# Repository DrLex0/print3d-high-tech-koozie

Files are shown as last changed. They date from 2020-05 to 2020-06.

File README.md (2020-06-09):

# High-tech Koozie (customizable)
*3D printable Customizable high-tech cooler (koozie) for cans and bottles (formerly thing:1771124 and thing:3927994)*

### License
[Creative Commons - Attribution - Non Commercial - Share Alike](https://creativecommons.org/licenses/by-nc-sa/4.0/)

For the legally impaired: my interpretation of the *non-commercial* aspect of this license, is that you cannot make profits from either the 3D models generated by this customizer, or physical 3D prints. Read the entire LICENSE file for the fine details. I have no objections against selling 3D prints of this model at no more than strictly the cost of used material and electricity.

### Gallery

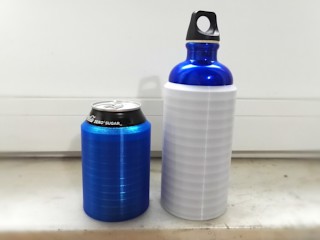
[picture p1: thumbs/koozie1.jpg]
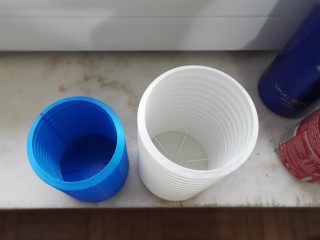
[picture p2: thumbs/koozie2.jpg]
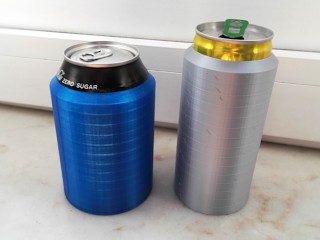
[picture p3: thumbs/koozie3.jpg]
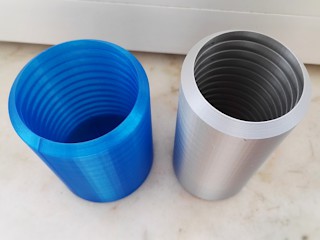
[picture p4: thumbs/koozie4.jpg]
[🔎](images/koozie1.jpg) [🔎](images/koozie2.jpg) [🔎](images/koozie3.jpg) [🔎](images/koozie4.jpg)

## Description and Instructions

OK, I admit, it's just a piece of plastic, therefore ‘high tech’ may be a bit exaggerated.
Still, this is not your average soda can cooler, or ‘koozie’ as it is sometimes called. This one has no inner shell, instead it relies on the can itself to seal the air inside. This has the benefit of minimizing the material needed hence lighter weight, as well as a minimal contact area with the plastic such that it maximally relies on air for insulation: air is a better thermal insulator than most if not all plastics. To further improve insulation, the zone between the can and the outer walls is divided into horizontal compartments to reduce convection.

This is a **customizable parametric model** made in OpenSCAD. A ready-to-print model for the ubiquitous 330 ml can can be found in the examples folder, but if you have a different size of can or bottle, just **[use OpenSCAD's Customizer](https://www.dr-lex.be/3d-printing/customizer.html)** to generate a model tailored to it. The only condition is that the bottle's lower part is a nearly perfect cylinder.

When creating your own model in Customizer, the most important parameters are the diameter of the can and its height you want to be covered by the koozie. To get a tight fit without having to push or tug on the can, make sure to either accurately measure the diameter, or just look it up in specification sheets from can or bottle manufacturers. The JSON file contains a few presets with accurate diameters that can be loaded in the customizer interface inside OpenSCAD.
The *air gap* determines the distance between the outside of the can/bottle (plus tolerance) and the outer wall. I usually set this to between 4 and 5 mm. More will obviously offer better insulation, but also makes the thing fatter and unwieldy.

This works equally well in rigid and flexible filaments. A flexible filament is recommended for robustness, for instance the koozie for the SIGG bottle in the photos was printed with rigid.ink flexible PLA.

Depending on what material you print in, to compensate for shrinkage of the material when it cools down after printing, you may need to slightly scale up the model or generate it with either a larger tolerance or larger diameter. Flexible filaments tend to shrink considerably but since they're flexible, it usually also isn't too bad if the model is slightly too tight. To avoid spending hours and material on a print and then noticing it is too tight or sloppy, the customizer has an option `test_slice` that will generate a minimal model that can be quickly printed for testing the fit.
 

### Print settings

I print these at 0.2 mm layers, with the slicer set to 20% infill, with no raft and no supports. If you're using Slic3r/PrusaSlicer, I recommend turning off “detect thin walls.”

Despite its apparent complexity, this is an easy print because all overhangs are 45° and they are convex. Do not try to enable supports because it could only result in a terrible and unnecessary mess.

For an efficient print, match the extrusion width to the wall thickness(es) you have configured in customizer. Some slicers like PrusaSlicer will tell you the optimal wall widths for your current set of print settings. The example models were generated with thicknesses that should print with 2 perimeters on a 0.4 mm nozzle.

Infill is only relevant for the small outer ring at the bottom. You can use 100% infill for the strongest result, but normally you will want to use the lowest infill value possible.
 

### Does this really work?

I tested the difference between a 330 ml can inside this cooler compared to a bare can, both starting at 3°C in a room at 23°C. After one hour, the can in the cooler was at 10.4°C, the other one at 14.6°C. This was with the cooler starting out at room temperature. If you would refrigerate the koozie as well before using it, it would keep your drink cool for a slightly longer time.
 

## Updates

### 2018/07/01
Added a slight chamfer to the models to make the bottom edges less sharp, and provided ‘xBtm’ models with a thicker bottom.

### 2019/07/13
Added model for 250 ml energy drink cans.

### 2019/10/20
Made the model customizable, such that it is much easier to generate this kind of koozie for any (cylindrical) shape of can or bottle.

### 2019/11/13: v1.3
Avoid risk of non-manifold model (thanks to Lyl3 for reporting this).

## Tags
`customizer`, `openscad`, `beer`, `beer_can`, `cooler`, `Insulator`, `Koozie`, `soda`, `soda_can`, `thermos`, `bottle`

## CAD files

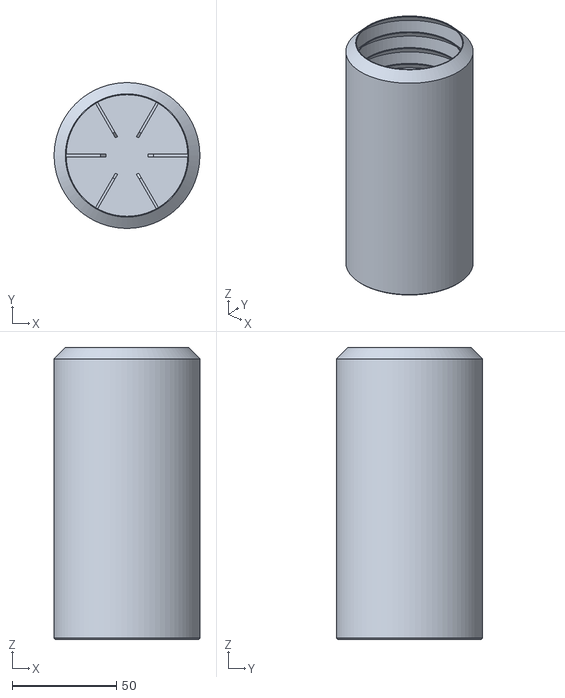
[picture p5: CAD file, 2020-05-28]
examples/Sleek330mlCan.stl
69.8 x 69.8 x 139.8

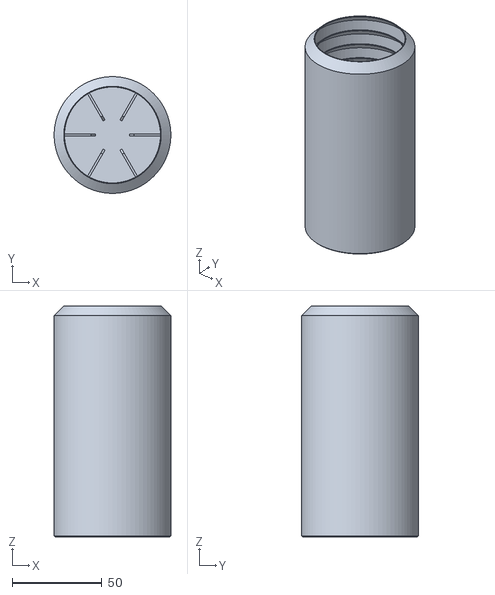
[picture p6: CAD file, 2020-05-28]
examples/EnergyDrink250mlCan.stl
65.1 x 65.1 x 128.8

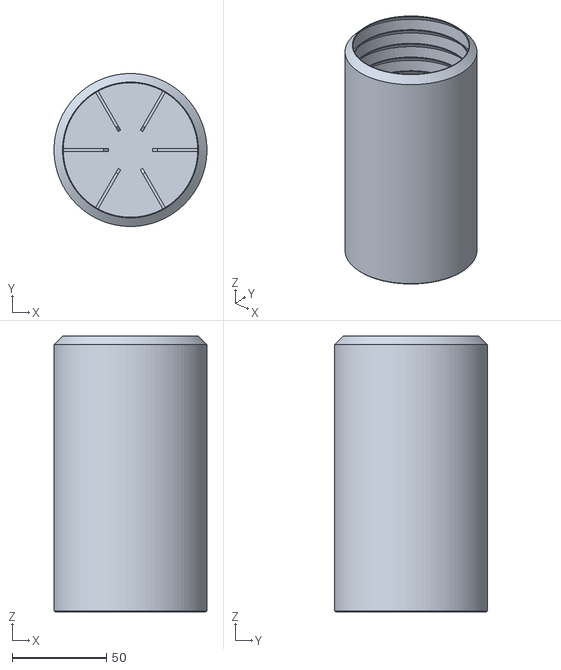
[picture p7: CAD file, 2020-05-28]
examples/SIGGBottle600ml.stl
81.0 x 81.0 x 146.2

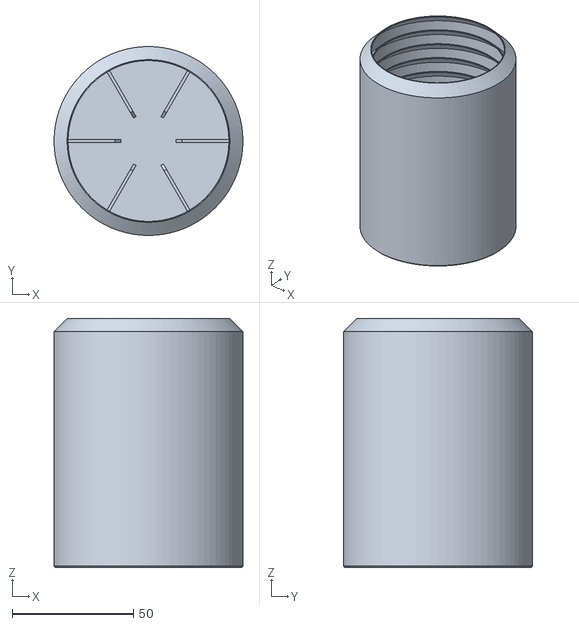
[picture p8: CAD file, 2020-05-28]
examples/Standard330mlCan.stl
78.0 x 78.0 x 102.8

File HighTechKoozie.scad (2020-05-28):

/* Customizable High-tech Koozie
 * By DrLex, v1.2 2019/11
 * Thingiverse thing:3927994
 * Based on original High-Tech Soda Can Cooler, thing:1771124
 * Released under Creative Commons - Attribution - Non-Commercial - Share Alike license */

/* [Dimensions] */
// Diameter of the cylinder that fits in the koozie. All dimensions are in mm.
can_dia = 66.2; //[10:0.1:240]

// Height of the cylinder covered by the koozie.
can_height = 99.0; //[1:0.1:250]

// Tolerance between the can and the koozie. Use this to compensate for printing inaccuracies and material shrinkage.
tolerance = 0.10; //[0:0.01:1]

// Space between the can and the outer wall. Larger values offer better insulation, smaller values a sleeker design.
air_gap = 5.0; //[0.1:0.1:30]

// Sliced wall thickness of the inner baffles. Preferably set this to a value that will yield exactly 1, 2, or another integer number of perimeters.
baffle_wall = 0.76; //[0.1:0.01:2]

// Outer wall thickness. Avoid using values smaller than baffle_wall.
outer_wall = 0.76; //[0.1:0.01:2]

// Bottom thickness
bottom_thick = 0.80; //[0.1:0.01:2]

// Generate only the topmost part with 2 baffles, for making a test print to check for correct fit.
test_slice = "no"; //[yes, no]


/* [Advanced] */

// Vertical distance between the baffles
baffle_dist = 8.0; //[1:0.1:30]

// Height of the support/reinforcement bars in the bottom
support_height = 3.0; //[0:0.1:10]

// Width of the support bars in the bottom
support_width = 1.2; //[0.1:0.01:3]

// Number of segments (detail) in the cylinders. At lower values, the effective inside diameter will be smaller than expected.
segments = 80; //[16:128]

// Cut off the top edge of the baffles to avoid a very thin single-line extrusion that tends to detach when sliding cans into the koozie. This must be well below baffle_wall to maintain correct dimensions.
top_cut = 0.4; //[0:0.01:1]

/* [Hidden] */
outer_dia = can_dia + 2*(tolerance + air_gap + outer_wall);
chamfer = 0.6;
in_wall_radius = outer_dia/2 - outer_wall;
inside_radius = can_dia / 2 + tolerance;
// Make uncut baffles wide enough for good overlap
baffle_radius = outer_dia / 2 + baffle_wall + .5;
baffle_cut = (outer_dia  - outer_wall) / 2;  // in the middle of the outer wall
baffle_height = in_wall_radius - inside_radius + baffle_wall - top_cut;  // effective height
num_comparts = floor((can_height - baffle_height) / baffle_dist);
baffle_offset = can_height - baffle_height - (num_comparts * baffle_dist);

cylinder_h = bottom_thick + support_height + can_height - baffle_height - (outer_wall -baffle_wall);
inside_chamfer = max(chamfer, 0.8 * support_height);

gap_fill_r = outer_dia/2 - baffle_wall/2;

echo(["Outer diameter", outer_dia]);
echo(["Baffle height", baffle_height]);
echo(["Number of compartments", num_comparts]);

if(test_slice == "yes") {
    total_h = bottom_thick + support_height + can_height;
    shift = total_h - baffle_height - baffle_dist - 3;
    chop_r = total_h/2 + 1;
    difference() {
        // Not very efficient computation-wise, but easy
        translate([0, 0, -shift]) koozie();
        translate([0, 0, -chop_r]) cube(2*chop_r, center=true);
        // Remove any leftovers of lower baffles
        translate([0, 0, -.2]) cylinder(r2=0, r1=in_wall_radius, h=in_wall_radius, $fn=segments);
    }
}
else {
    koozie();
}


// Generate one baffle, positioned such that the lower intersection with the inside wall is at z=0.
module baffle()
{
    shift = baffle_radius - in_wall_radius - baffle_wall;
    translate([0, 0, -shift])
    difference() {
        cylinder(r2=0, r1=baffle_radius, h=baffle_radius, $fn=segments);
        translate([0, 0, -baffle_wall]) cylinder(r2=0, r1=baffle_radius, h=baffle_radius, $fn=segments);
        if(top_cut > 0) {
            translate([0, 0, baffle_height + baffle_radius + shift]) cube(2*baffle_radius, center=true);
        }
    }
}

module koozie()
{
    translate([0, 0, bottom_thick + support_height + baffle_offset]) {
        difference() {
            union() {
                if(num_comparts > 0) {
                    intersection() {
                        union() {
                            for(i = [0: 1: num_comparts-1]) {
                                translate([0, 0, i*baffle_dist]) baffle();
                            }
                        }
                        cylinder(r=baffle_cut, h=can_height+10, $fn=segments);
                    }
                }
                intersection() {
                    translate([0, 0, num_comparts*baffle_dist]) baffle();
                    cylinder(r=outer_dia/2, h=can_height+10, $fn=segments);
                }
            }

            cylinder(r=inside_radius, h=can_height+baffle_radius+10, $fn=segments);
        }
    }
    intersection() {
        union() {
            difference() {
                union() {
                    cylinder(r=outer_dia/2, h=cylinder_h, $fn=segments);
                    if(outer_wall >= baffle_wall) {
                        translate([0, 0, cylinder_h]) cylinder(r1=gap_fill_r, r2=0, h=gap_fill_r, $fn=segments);
                    }
                }
                translate([0, 0, bottom_thick]) {
                    intersection() {
                        cylinder(r=in_wall_radius, h=can_height + bottom_thick + support_height + outer_dia, $fn=segments);
                        translate([0, 0, inside_chamfer - in_wall_radius]) cylinder(r1=0, r2=cylinder_h+outer_dia, h=cylinder_h+outer_dia, $fn=segments);
                    }
                }
            }
            if(support_height > 0) {
                difference() {
                    translate([0, 0, bottom_thick + support_height/2]) for(i = [0:1:2]) {
                        rotate([0, 0, 60*i]) cube([outer_dia - outer_wall, support_width, support_height], center=true);
                    }
                    translate([0, 0, bottom_thick-outer_dia/6]) rotate([0,0,30]) cylinder(r1=0, r2=outer_dia/3, h=outer_dia/3, $fn=6);
                }
            }
        }
        // Intersect with a cone to create the chamfer
        translate([0, 0, chamfer - outer_dia/2]) cylinder(r1=0, r2=cylinder_h+outer_dia, h=cylinder_h+outer_dia, $fn=segments);
    }
}

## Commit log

2020-05-28 Thingiverse exodus model 11: migrate to GitHub
    [EnergyDrink250mlCan.stl, HighTechKoozie.scad, SIGGBottle600ml.stl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]
2020-06-09 Move file to examples
    [EnergyDrink250mlCan.stl]
